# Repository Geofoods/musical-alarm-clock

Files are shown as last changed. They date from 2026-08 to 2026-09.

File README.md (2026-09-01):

# Musical Alarm Clock







An alarm clock with a Seeed Studio XIAO ESP32, a TFT display, and a piezo buzzer. The project includes firmware, a custom PCB, and a 3D-printed enclosure.

## Features

- Large clock display on a 320×240 TFT screen
- Piezo buzzer alarm with "WAKE UP!" visual alert
- 4-button interface for setting the alarm hour/minute
- Configurable alarm time with a simple state-machine UI
- Compact 90mm × 48.5mm PCB form factor
- Plays a unique melody for the alarm

## BOM

I know the kit comes with an active buzzer which only plays sounds at one frequency so I have my own passive buzzer which can play more different frequencies meaning I can play melodies

| Quantity | Component |
| --- | --- |
| 1 | Custom PCB |
| 1 | 3D Printed Case |
| 1 | Seeed XIAO ESP32 |
| 1 | 2.25-inch TFT Screen |
| 4 | MX-Style Switches |
| 4 | White DSA keycaps |
| 1 | 3.3V Piezo Passive Buzzer |
| 4 | M3x16mm screws |
| 4 | M3x5x4mm heatset inserts |
| 1 | 2.54mm 8 Pin Male Header |
| 8 | 20cm Female-Female Jumper Wires |

Got the music from this [buzzer repository](https://github.com/hibit-dev/buzzer)

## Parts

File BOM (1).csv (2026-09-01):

Item # | Quantity | Component
1 | 1 | Custom PCB
2 | 1 | 3D Printed Case
3 | 1 | Seeed XIAO ESP32
4 | 1 | 2.25inch TFT Screen
5 | 4 | MX-Style Switches
6 | 4 | White DSA keycaps
7 | 9 | 3.3V Piezo Buzzer
8 | 4 | M3x16mm screws
9 | 4 | M3x5mx4mm heatset inserts
10 | 1 | 2.54mm 8 Pin Male Header
11 | 8 | 20cm Female-Female Jumper Wires

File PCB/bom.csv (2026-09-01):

Reference | Value | Footprint | Quantity | Description
U1 | XIAO-ESP32-C3 | Seeed_Studio_XIAO_Series:XIAO-ESP32-C3-DIP | 1 | Seeed Studio XIAO ESP32-C3 microcontroller
J1 | Conn_01x08_Pin | Connector_PinSocket_2.54mm:PinSocket_1x08_P2.54mm_Vertical | 1 | 1x8 2.54mm header (display connector)
BZ1 | Buzzer | Buzzer_Beeper:Buzzer_12x9.5RM7.6 | 1 | Piezo buzzer 12x9.5mm RM7.6
SW1 | SW_Push | Button_Switch_Keyboard:SW_Cherry_MX_1.00u_PCB | 1 | Push button (decrement)
SW2 | SW_Push | Button_Switch_Keyboard:SW_Cherry_MX_1.00u_PCB | 1 | Push button (increment)
SW3 | SW_Push | Button_Switch_Keyboard:SW_Cherry_MX_1.00u_PCB | 1 | Push button (mode)
SW4 | SW_Push | Button_Switch_Keyboard:SW_Cherry_MX_1.00u_PCB | 1 | Push button (cancel/confirm)
H1 | MountingHole | MountingHole:MountingHole_3.2mm_M3 | 1 | Mounting hole M3
H2 | MountingHole | MountingHole:MountingHole_3.2mm_M3 | 1 | Mounting hole M3
H3 | MountingHole | MountingHole:MountingHole_3.2mm_M3 | 1 | Mounting hole M3
H4 | MountingHole | MountingHole:MountingHole_3.2mm_M3 | 1 | Mounting hole M3

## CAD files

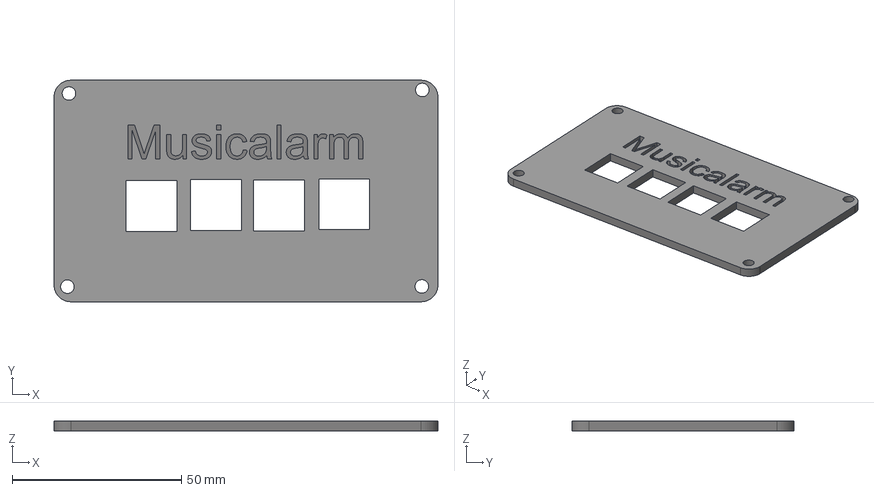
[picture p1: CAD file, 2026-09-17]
CAD/top.step
113.5 x 65.5 x 3.00 mm

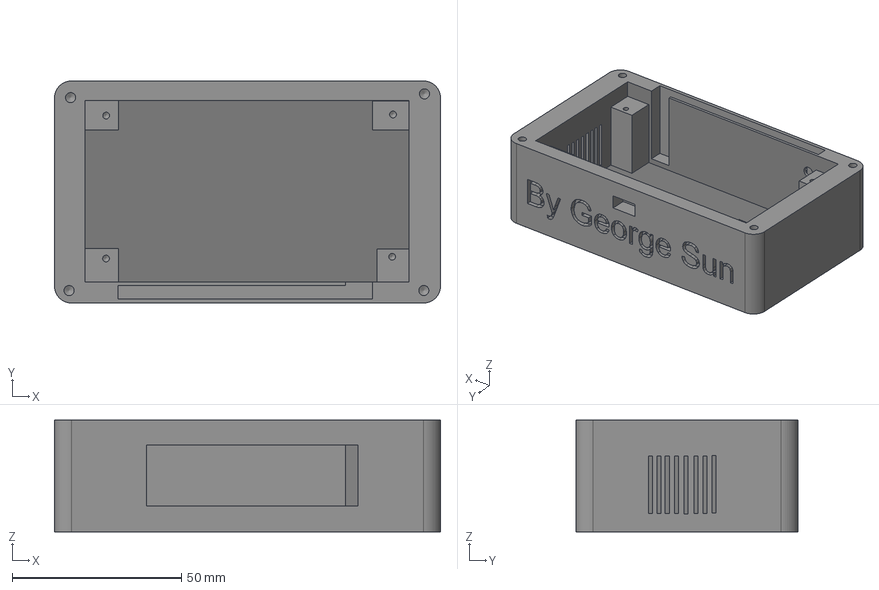
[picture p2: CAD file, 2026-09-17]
CAD/bottom.step
114.0 x 65.6 x 33.0 mm

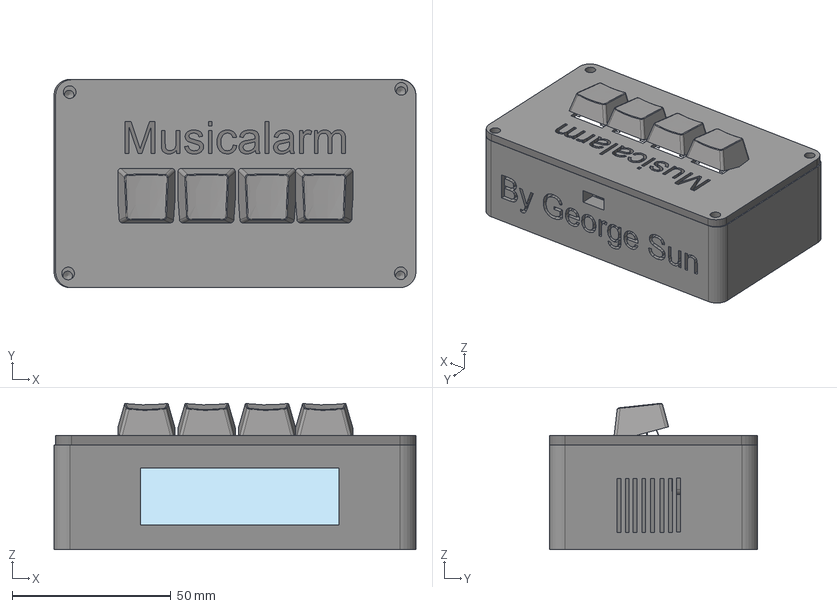
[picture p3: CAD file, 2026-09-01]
CAD/CAD.step
114.0 x 65.6 x 46.0 mm

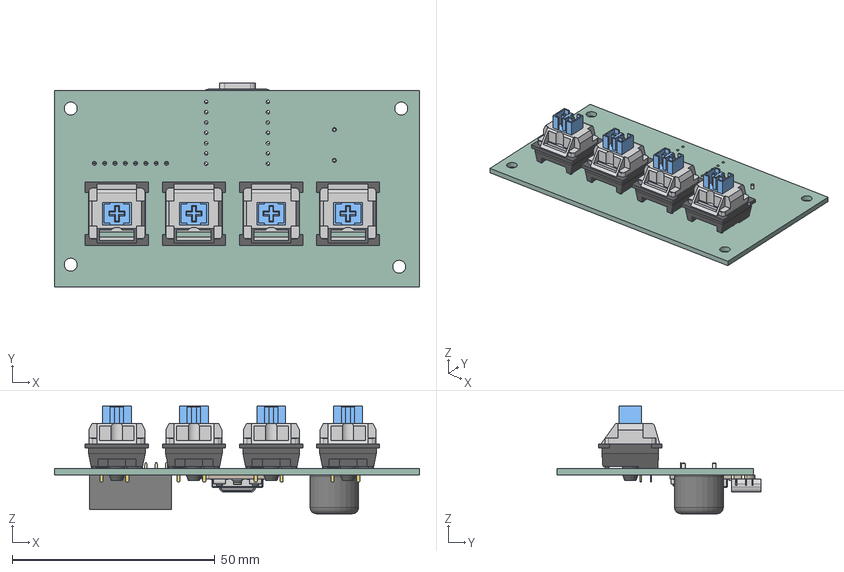
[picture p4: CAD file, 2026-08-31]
CAD/musicalalarmclock.step
90.0 x 50.3 x 26.5 mm
Button x 4
Pins x 4
PinSocket_1x08_P2.54mm_Vertical
Buzzer_12x95RM76
BOSS-EXTRUDE14_8_
BOSS-EXTRUDE7_4_
BOSS-EXTRUDE7_3_
BOSS-EXTRUDE14_4_
BOSS-EXTRUDE14_2_
BOSS-EXTRUDE14_11_
BOSS-EXTRUDE7_7_
BOSS-EXTRUDE14_9_
BOSS-EXTRUDE14_3_
BOSS-EXTRUDE14_7_
MIRROR2
BOSS-EXTRUDE14_5_
BOSS-EXTRUDE14_12_
BOSS-EXTRUDE7_8_
BOSS-EXTRUDE7_1_
BOSS-EXTRUDE14_10_
BOSS-EXTRUDE7_9_
BOSS-EXTRUDE14_6_
BOSS-EXTRUDE14_1_
BOSS-EXTRUDE7_6_
BOSS-EXTRUDE7_2_
CUT-EXTRUDE5
BOSS-EXTRUDE7_5_
U.FL Connector v1
Button (1) x 2
Shield
musicalalarmclock_PCB

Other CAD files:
CAD/bottom.stl
CAD/top.stl

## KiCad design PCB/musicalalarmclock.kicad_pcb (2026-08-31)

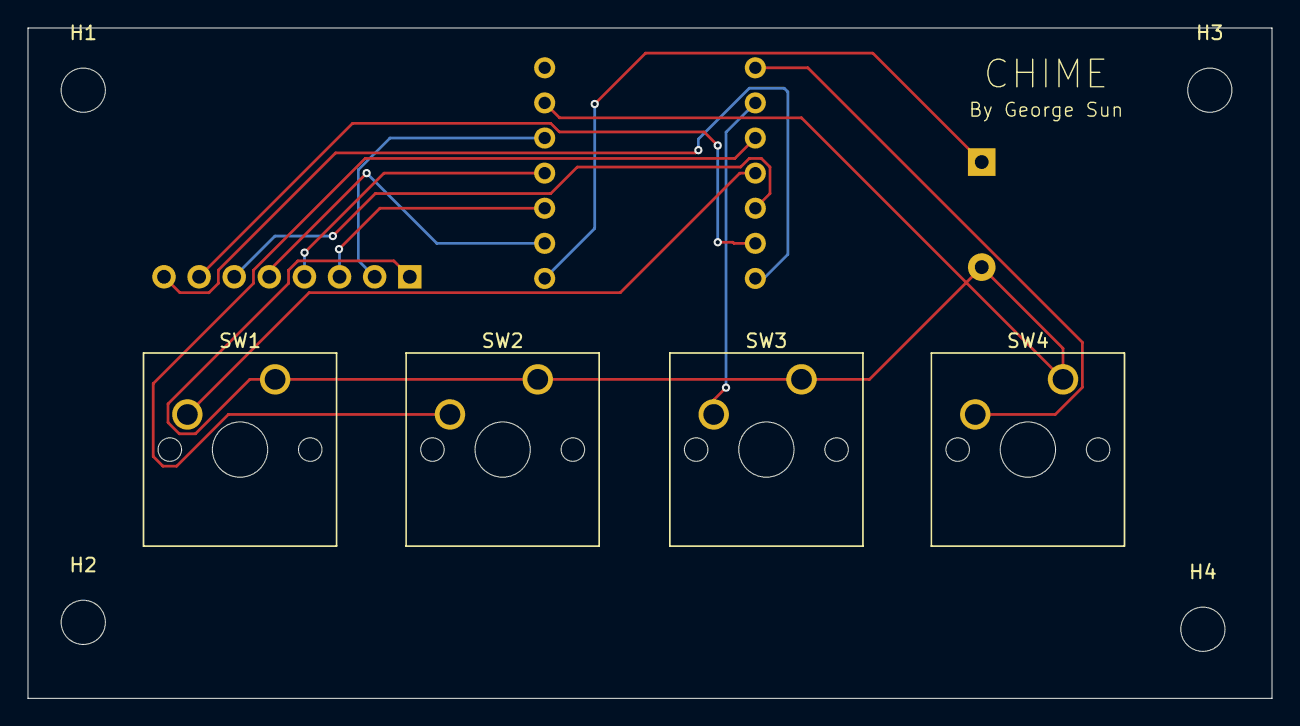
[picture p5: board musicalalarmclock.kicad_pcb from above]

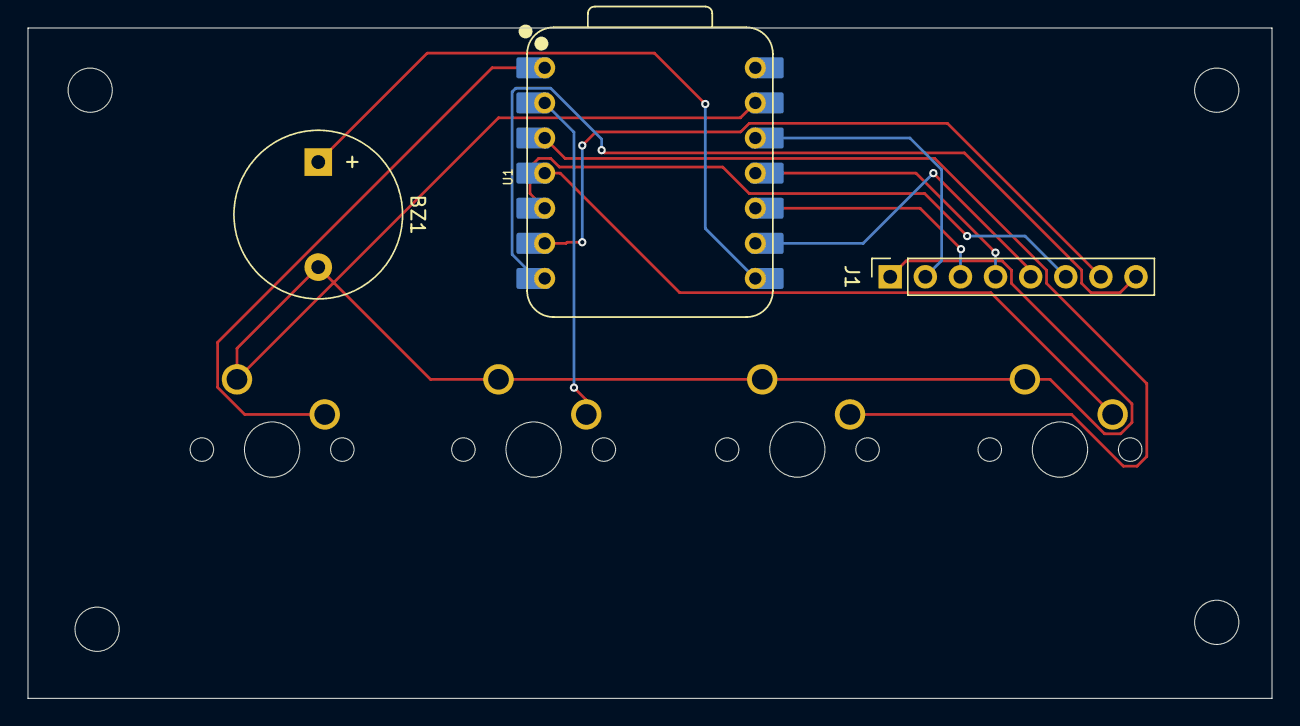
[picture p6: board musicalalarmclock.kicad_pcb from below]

Board: 2 copper layers, 90.0 x 48.5 mm, 11 parts (3 on the bottom side), 13 nets.

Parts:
BZ1: Buzzer; Buzzer_12x9.5RM7.6
H1, H2, H3, H4: MountingHole; MountingHole_3.2mm_M3
J1: Conn_01x08_Pin; PinSocket_1x08_P2.54mm_Vertical
SW1, SW2, SW3, SW4: SW_Push; SW_Cherry_MX_1.00u_PCB
U1: XIAO-ESP32-C3-SMD; XIAO-ESP32-C3-DIP

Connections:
+3.3V: J1.2, U1.12 (3V3_OUT)
/BL: J1.8, U1.7 (D6)
/CS: J1.7, U1.6 (D5)
/DC: J1.6, U1.5 (D4)
/RST: J1.5, U1.9 (D8)
/SCL: J1.3, U1.10 (D9/BOOT)
/SDA: J1.4, U1.11 (D10)
GND: BZ1.2 (-), J1.1, SW1.1, SW2.1, SW3.1, SW4.1, U1.13 (GND)
unnamed: BZ1.1 (+), U1.8 (D7)
unnamed: SW4.2, U1.1 (D0)
unnamed: SW3.2, U1.2 (D1)
unnamed: SW2.2, U1.3 (D2)
unnamed: SW1.2, U1.4 (D3)

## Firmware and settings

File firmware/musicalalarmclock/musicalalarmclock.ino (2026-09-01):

#include <Adafruit_GFX.h>
#include <Adafruit_GrayOLED.h>
#include <Adafruit_SPITFT.h>
#include <Adafruit_SPITFT_Macros.h>
#include <gfxfont.h>
#include <Adafruit_ST7789.h>
#include <SPI.h>
#if __has_include(<esp_random.h>)
#include <esp_random.h>
#define HW_RANDOM() esp_random()
#elif __has_include(<esp_system.h>)
#include <esp_system.h>
#define HW_RANDOM() esp_random()
#elif __has_include(<rng.h>)
#include <rng.h>
#define HW_RANDOM() rng_u32()
#else
#define HW_RANDOM() (micros())
#endif
#include "pitches.h"


#define TFT_SCLK 9
#define TFT_MOSI 10
#define TFT_RST 8
#define TFT_DC 6
#define TFT_CS 7
#define TFT_BL 21

#define SW1 5
#define SW2 4
#define SW3 3
#define SW4 2

#define BUZZER 20


const int melodyNeverGonnaGiveYouUp[] = {
  NOTE_A4, REST, NOTE_B4, REST, NOTE_C5, REST, NOTE_A4, REST,
  NOTE_D5, REST, NOTE_E5, REST, NOTE_D5, REST,

  NOTE_G4, NOTE_A4, NOTE_C5, NOTE_A4, NOTE_E5, NOTE_E5, REST,
  NOTE_D5, REST,

  NOTE_G4, NOTE_A4, NOTE_C5, NOTE_A4, NOTE_D5, NOTE_D5, REST,
  NOTE_C5, REST, NOTE_B4, NOTE_A4, REST,

  NOTE_G4, NOTE_A4, NOTE_C5, NOTE_A4, NOTE_C5, NOTE_D5, REST,
  NOTE_B4, NOTE_A4, NOTE_G4, REST, NOTE_G4, REST, NOTE_D5, REST, NOTE_C5, REST,

  NOTE_G4, NOTE_A4, NOTE_C5, NOTE_A4, NOTE_E5, NOTE_E5, REST,
  NOTE_D5, REST,

  NOTE_G4, NOTE_A4, NOTE_C5, NOTE_A4, NOTE_G5, NOTE_B4, REST,
  NOTE_C5, REST, NOTE_B4, NOTE_A4, REST,

  NOTE_G4, NOTE_A4, NOTE_C5, NOTE_A4, NOTE_C5, NOTE_D5, REST,
  NOTE_B4, NOTE_A4, NOTE_G4, REST, NOTE_G4, REST, NOTE_D5, REST, NOTE_C5, REST,

  NOTE_C5, REST, NOTE_D5, REST, NOTE_G4, REST, NOTE_D5, REST, NOTE_E5, REST,
  NOTE_G5, NOTE_F5, NOTE_E5, REST,

  NOTE_C5, REST, NOTE_D5, REST, NOTE_G4, REST
};

const int durationsNeverGonnaGiveYouUp[] = {
  8, 8, 8, 8, 8, 8, 8, 4,
  8, 8, 8, 8, 2, 2,

  8, 8, 8, 8, 2, 8, 8,
  2, 8,

  8, 8, 8, 8, 2, 8, 8,
  4, 8, 8, 8, 8,

  8, 8, 8, 8, 2, 8, 8,
  2, 8, 4, 8, 8, 8, 8, 8, 1, 4,

  8, 8, 8, 8, 2, 8, 8,
  2, 8,

  8, 8, 8, 8, 2, 8, 8,
  2, 8, 8, 8, 8,

  8, 8, 8, 8, 2, 8, 8,
  4, 8, 3, 8, 8, 8, 8, 8, 1, 4,

  2, 6, 2, 6, 4, 4, 2, 6, 2, 3,
  8, 8, 8, 8,

  2, 6, 2, 6, 2, 1
};

const int melodyStillDre[] = {
  NOTE_D3, REST, NOTE_D3, REST, NOTE_D3, REST, NOTE_D3, NOTE_D3, NOTE_D3, NOTE_A2, REST,
  NOTE_D3, REST, NOTE_D3, REST, NOTE_D3, REST, NOTE_D3, NOTE_D3, NOTE_D3, NOTE_A2, REST,
  NOTE_D3, REST, NOTE_D3, REST, NOTE_D3, REST, NOTE_D3, NOTE_D3, NOTE_D3, NOTE_A2, REST,
  NOTE_D3,
  NOTE_D4, REST, NOTE_D4, NOTE_D4, REST,
  NOTE_E3, NOTE_D3, NOTE_F3, REST, NOTE_F3,
  NOTE_D4, REST, NOTE_D4, NOTE_D4, REST,
  NOTE_D3,
  NOTE_D4, REST, NOTE_D4, NOTE_D4, REST,
  NOTE_E3, NOTE_D3, NOTE_F3, REST, NOTE_F3,
  NOTE_D4,
  REST
};

const int durationsStillDre[] = {
  8, 16, 8, 16, 8, 16, 10, 10, 10, 3, 2,
  8, 16, 8, 16, 8, 16, 10, 10, 10, 3, 2,
  8, 16, 8, 16, 8, 16, 10, 10, 10, 3, 2,
  4,
  4, 3, 4, 4, 3,
  6, 6, 6, 33, 6,
  4, 3, 4, 4, 3,
  4,
  4, 3, 4, 4, 3,
  6, 6, 6, 33, 6,
  3,
  1
};

const int melodyLivingOnAPrayer[] = {
  NOTE_B3, NOTE_D4, NOTE_E4, NOTE_E4,
  NOTE_B3, NOTE_D4, NOTE_E4, NOTE_E4,
  NOTE_B3, NOTE_D4, NOTE_E4, NOTE_E4,

  NOTE_B3, NOTE_D4, NOTE_G4, NOTE_G4, NOTE_G4, NOTE_FS4, NOTE_E4, NOTE_D4, NOTE_E4, NOTE_E4, NOTE_D4,
  NOTE_B3,

  NOTE_G4, NOTE_G4, NOTE_FS4, NOTE_E4, NOTE_E4, NOTE_FS4,
  NOTE_G4, NOTE_FS4, NOTE_E4, NOTE_E4, NOTE_B3,
  NOTE_A3, NOTE_G3,

  REST
};

const int durationsLivingOnAPrayer[] = {
  8, 8, 8, 8,
  8, 8, 8, 8,
  8, 8, 8, 8,

  8, 8, 8, 8, 8, 8, 8, 8, 8, 16, 16,
  1,

  8, 8, 8, 8, 4, 8,
  4, 4, 8, 4, 4,
  8, 1,

  1
};

const int melodyIceIceBaby[] = {
  NOTE_A5, NOTE_A5, NOTE_A5, NOTE_A5, NOTE_A5, NOTE_A5, NOTE_A5, NOTE_A5, NOTE_A5, NOTE_A5, NOTE_A5,
  NOTE_G5, NOTE_G5, NOTE_G5, NOTE_G5, NOTE_G5,
  NOTE_A5, NOTE_A5, NOTE_A5, NOTE_A5, NOTE_A5, NOTE_A5, NOTE_A5, NOTE_A5, NOTE_A5, NOTE_A5, NOTE_A5,
  NOTE_G5, NOTE_G5, NOTE_G5, NOTE_G5, NOTE_G5,

  NOTE_A5, NOTE_A5,
  NOTE_G5, NOTE_G5,
  NOTE_A5, NOTE_A5,
  NOTE_G5, NOTE_G5
};

const int durationsIceIceBaby[] = {
  5, 5, 5, 5, 5, 5, 5, 5, 5, 5, 5,
  5, 5, 5, 5, 5,
  5, 5, 5, 5, 5, 5, 5, 5, 5, 5, 5,
  5, 5, 5, 5, 5,

  1, 2,
  1, 2,
  1, 2,
  1, 2
};

struct Song {
  const int* notes;
  const int* durations;
  int length;
};

const Song songs[] = {
  { melodyNeverGonnaGiveYouUp, durationsNeverGonnaGiveYouUp, sizeof(melodyNeverGonnaGiveYouUp) / sizeof(melodyNeverGonnaGiveYouUp[0]) },
  { melodyIceIceBaby, durationsIceIceBaby, sizeof(melodyIceIceBaby) / sizeof(melodyIceIceBaby[0]) },
  { melodyLivingOnAPrayer, durationsLivingOnAPrayer, sizeof(melodyLivingOnAPrayer) / sizeof(melodyLivingOnAPrayer[0]) },
  { melodyStillDre, durationsStillDre, sizeof(melodyStillDre) / sizeof(melodyStillDre[0]) }
};

const int NUM_SONGS = sizeof(songs) / sizeof(songs[0]);
int songIndex = 0;
int melodyIndex = 0;
unsigned long noteStartTime = 0;


class MyST7789 : public Adafruit_ST7789 {
public:
  MyST7789(int8_t cs, int8_t dc, int8_t mosi, int8_t sclk, int8_t rst)
    : Adafruit_ST7789(cs, dc, mosi, sclk, rst) {}

  void setOffsets(uint8_t col, uint8_t row) {
    _colstart = _colstart2 = col;
    _rowstart = _rowstart2 = row;
  }
};

MyST7789 tft(TFT_CS, TFT_DC, TFT_MOSI, TFT_SCLK, TFT_RST);

int hours = 12;
int minutes = 0;
int seconds = 0;

int alarmHour = 12;
int alarmMinute = 0;


uint8_t alarmEditState = 0;

bool alarmRinging = false;
bool alarmTriggeredThisMinute = false;

bool lastSW1 = HIGH;
bool lastSW2 = HIGH;
bool lastSW3 = HIGH;
bool lastSW4 = HIGH;

unsigned long lastButtonTime = 0;
const unsigned long debounceTime = 150;

void drawTime() {
  tft.fillRect(0, 45, 320, 100, ST77XX_BLACK);

  if (alarmEditState > 0) {
    tft.setTextSize(2);
    tft.setCursor(95, 35);

    if (alarmEditState == 1) {
      tft.setTextColor(ST77XX_YELLOW);
      tft.print("SET HOUR ");
    } else if (alarmEditState == 2) {
      tft.setTextColor(ST77XX_MAGENTA);
      tft.print("SET MINUTE");
    }

    tft.setTextSize(6);
    tft.setCursor(20, 65);

    if (alarmEditState == 1) tft.setTextColor(ST77XX_CYAN);
    else tft.setTextColor(ST77XX_WHITE);

    if (alarmHour < 10) tft.print("0");
    tft.print(alarmHour);

    tft.setTextColor(ST77XX_WHITE);
    tft.print(":");

    if (alarmEditState == 2) tft.setTextColor(ST77XX_CYAN);
    else tft.setTextColor(ST77XX_WHITE);

    if (alarmMinute < 10) tft.print("0");
    tft.print(alarmMinute);
  }
  else if (alarmRinging) {
    tft.setTextColor(ST77XX_RED);
    tft.setTextSize(2);
    tft.setCursor(110, 35);
    tft.print("WAKE UP!");

    tft.setTextSize(6);
    tft.setCursor(20, 65);

    if (hours < 10) tft.print("0");
    tft.print(hours);
    tft.print(":");

    if (minutes < 10) tft.print("0");
    tft.print(minutes);
  }
  else {
    tft.setTextColor(ST77XX_GREEN);
    tft.setTextSize(6);
    tft.setCursor(20, 55);

    if (hours < 10) tft.print("0");
    tft.print(hours);
    tft.print(":");

    if (minutes < 10) tft.print("0");
    tft.print(minutes);
  }
}

void drawAlarmInfo() {
  tft.fillRect(0, 145, 320, 45, ST77XX_BLACK);

  tft.setTextColor(ST77XX_WHITE);
  tft.setTextSize(2);
  tft.setCursor(75, 155);

  tft.print("ALARM ");

  if (alarmHour < 10) tft.print("0");
  tft.print(alarmHour);
  tft.print(":");

  if (alarmMinute < 10) tft.print("0");
  tft.print(alarmMinute);
}

void updateClock() {
  static unsigned long lastSecond = 0;
  unsigned long now = millis();

  if (now - lastSecond >= 1000) {
    lastSecond += 1000;
    seconds++;

    if (seconds >= 60) {
      seconds = 0;
      minutes++;
    }

    if (minutes >= 60) {
      minutes = 0;
      hours++;
    }

    if (hours >= 24) {
      hours = 0;
    }

    alarmTriggeredThisMinute = false;
  }
}

void playAlarmMelody() {
  if (melodyIndex >= songs[songIndex].length) {
    noTone(BUZZER);
    return;
  }

  int note = songs[songIndex].notes[melodyIndex];
  int noteDuration = 1000 / songs[songIndex].durations[melodyIndex];
  unsigned long now = millis();

  if (now - noteStartTime >= noteDuration) {
    noteStartTime = now;
    if (note != REST) {
      tone(BUZZER, note, noteDuration);
    } else {
      noTone(BUZZER);
    }
    melodyIndex++;
  }
}

void startAlarm() {
  songIndex = random(NUM_SONGS);
  alarmRinging = true;
  alarmTriggeredThisMinute = true;
  melodyIndex = 0;
  noteStartTime = 0;
  drawTime();
}

void stopAlarm() {
  alarmRinging = false;
  noTone(BUZZER);
  drawTime();
}

void checkAlarm() {
  if (alarmEditState > 0 || alarmRinging) {
    return;
  }

  if (hours == alarmHour && minutes == alarmMinute && !alarmTriggeredThisMinute) {
    startAlarm();
  }
}

void checkButtons() {
  bool sw1 = digitalRead(SW1);
  bool sw2 = digitalRead(SW2);
  bool sw3 = digitalRead(SW3);
  bool sw4 = digitalRead(SW4);

  unsigned long now = millis();

  if (now - lastButtonTime < debounceTime) {
    return;
  }


  if (lastSW1 == HIGH && sw1 == LOW) {
    lastButtonTime = now;
    if (alarmEditState == 1) {
      alarmHour = (alarmHour - 1 + 24) % 24;
      drawTime();
      drawAlarmInfo();
    } else if (alarmEditState == 2) {
      alarmMinute = (alarmMinute - 1 + 60) % 60;
      drawTime();
      drawAlarmInfo();
    }
  }


  if (lastSW2 == HIGH && sw2 == LOW) {
    lastButtonTime = now;
    if (alarmEditState == 1) {
      alarmHour = (alarmHour + 1) % 24;
      drawTime();
      drawAlarmInfo();
    } else if (alarmEditState == 2) {
      alarmMinute = (alarmMinute + 1) % 60;
      drawTime();
      drawAlarmInfo();
    }
  }


  if (lastSW3 == HIGH && sw3 == LOW) {
    lastButtonTime = now;
    if (!alarmRinging) {
      alarmEditState = (alarmEditState + 1) % 3;
      drawTime();
    }
  }


  if (lastSW4 == HIGH && sw4 == LOW) {
    lastButtonTime = now;
    if (alarmEditState > 0) {
      alarmEditState = 0;
      drawTime();
    } else if (alarmRinging) {
      stopAlarm();
    }
  }

  lastSW1 = sw1;
  lastSW2 = sw2;
  lastSW3 = sw3;
  lastSW4 = sw4;
}

void setup() {
  Serial.begin(115200);
  randomSeed(HW_RANDOM());

  pinMode(SW1, INPUT_PULLUP);
  pinMode(SW2, INPUT_PULLUP);
  pinMode(SW3, INPUT_PULLUP);
  pinMode(SW4, INPUT_PULLUP);

  pinMode(BUZZER, OUTPUT);
  digitalWrite(BUZZER, LOW);

  pinMode(TFT_BL, OUTPUT);
  digitalWrite(TFT_BL, LOW);

  tft.init(76, 284);
  tft.setOffsets(82, 18);
  tft.invertDisplay(false);
  tft.setRotation(1);

  tft.fillScreen(ST77XX_BLACK);

  drawTime();
  drawAlarmInfo();
}

void loop() {
  updateClock();
  checkButtons();
  checkAlarm();

  if (alarmRinging) {
    playAlarmMelody();
  }

  static unsigned long lastDisplayUpdate = 0;
  if (millis() - lastDisplayUpdate >= 500) {
    lastDisplayUpdate = millis();
    drawTime();
    drawAlarmInfo();
  }
}

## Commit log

2026-08-29 schematic and pcb
    [musicalalarmclock.kicad_pcb, musicalalarmclock.kicad_sch]
2026-08-31 getting 3d models
    [musicalalarmclock.kicad_pcb, musicalalarmclock.step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]
2026-08-31 cad model
    [CAD.step]
2026-09-01 add bom
    [BOM (1).csv]
2026-09-01 Revise BOM column headers and component names
    Updated column names and corrected component descriptions.
    [BOM (1).csv]
2026-09-01 Update README to correct ESP32 model reference
2026-09-01 Add BOM section to README
    Added Bill of Materials (BOM) section with components.
2026-09-01 Update BOM table formatting in README.md
2026-09-01 Add alarm melody and BOM
    - Play Für Elise on the buzzer when the alarm wakes you up (tone()/noTone())
    - Add pitches.h note definitions
    - Add PCB/bom.csv
    [bom.csv]
2026-09-17 add the different parts
    [bottom.step, top.step]
2026-09-17 gerber and stl
    [bottom.stl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]
